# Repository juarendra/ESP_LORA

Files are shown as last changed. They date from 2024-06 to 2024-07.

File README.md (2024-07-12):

# ESP_LORA

ESP-LORA By [Positron Electronik](https://www.tokopedia.com/positronelectronic?source=universe&st=product) is a High-end Development Board with an [ARDUINO UNO-like](https://www.google.com/search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) format, which will speed up your time to make your DIY projects easier.
This board is based on the [ESP32 microcontroller](https://www.espressif.com/sites/default/files/documentation/esp32-wroom-32_datasheet_en.pdf) which makes it an AI-enabled device and is recommended as an Edge Device.
The ESP-LORA By [Positron Electronik](https://www.tokopedia.com/positronelectronic?source=universe&st=product) has three power source inputs -USB, LiPo Battery, DC Jack- that can carry out these options simultaneously. If you use a DC Jack you will get a PSU with a Voltage of 5V 3A.

This board has a LI-PO battery charging feature with a max voltage of 4.2, equipped with Charging Protection so that charging your battery can be done more safely, the charging process can only be done with a USB power source.
By default, the [ESP32 microcontroller](https://www.espressif.com/sites/default/files/documentation/esp32-wroom-32_datasheet_en.pdf) is included with WiFi and Bluetooth Low Energy. This connectivity is even expanded with the presence of the [RFM95W](https://cdn.sparkfun.com/assets/a/e/7/e/b/RFM95_96_97_98W.pdf) LoRa(WAN) module. LoRa(WAN) has a good reputation for low power consumption, complementing the [ESP32 microcontroller](https://www.espressif.com/sites/default/files/documentation/esp32-wroom-32_datasheet_en.pdf)'s sleep mode, making this board even more useful in low-power ecosystems. In conclusion, this is the most appropriate solution for your IoT application.

In terms of design, this board is also equipped with an Industrial SHT21 Hum Temp Sensor and 0.91 inch Oled Display

## Table of Content

* [Product Specsification](#product-specsification)
* [Technical Spesification](#technical-spesification)
* [Priview Hardware](#priview-hardware)
* [Documentation](#documentation)
  * [Pinout Diagram](#pinout-diagram)
  * [Dimension](#dimension)
  * [BOM](#bom)
  * [Schematic](#schematic0)
  * [Example Program](#examples-program)
* [FAQ](#FAQ)

## Product Specsification

* ESP32 as Microcontroller Ready for AI (Tensilica Xtensa single-/dual-core 32-bit LX6 microprocessor(s))
* WiFi & BLE Connectivity 
* LoRa/LoRaWAN Connectivity
* Industrial Temperature Humidity Sensor
* Display Oled 0.91 inch
* Battery Input 1s LiPo with Battery Protection
* Big Power PSU 5V 3A
* Sparated PSU for Microcontroller and LORA

## Technical Spesification

| Features | Value |  
| --- | --- |
| Microcontroller | ESP32 |
| LoRa(WAN) Chip | RFM95W |
| LoRa(WAN) Base Freq | 915 MHz |
| LoRa(WAN) Freq Range | 902-928 MHz |
| Industrial Temperature Humidity Sensor | SHT21 |
| Dispaly | OLED 0.91 inch |
| Main PSU | LM2596 5-30VDC to 5V 3A |
| PSU ESP32 | M3406 2.0V to 6.0V to 3.3V 800mA|
| PSU LORA | M3406 2.0V to 6.0V to 3.3V 800mA| 

## Priview Hardware
<p align="center">
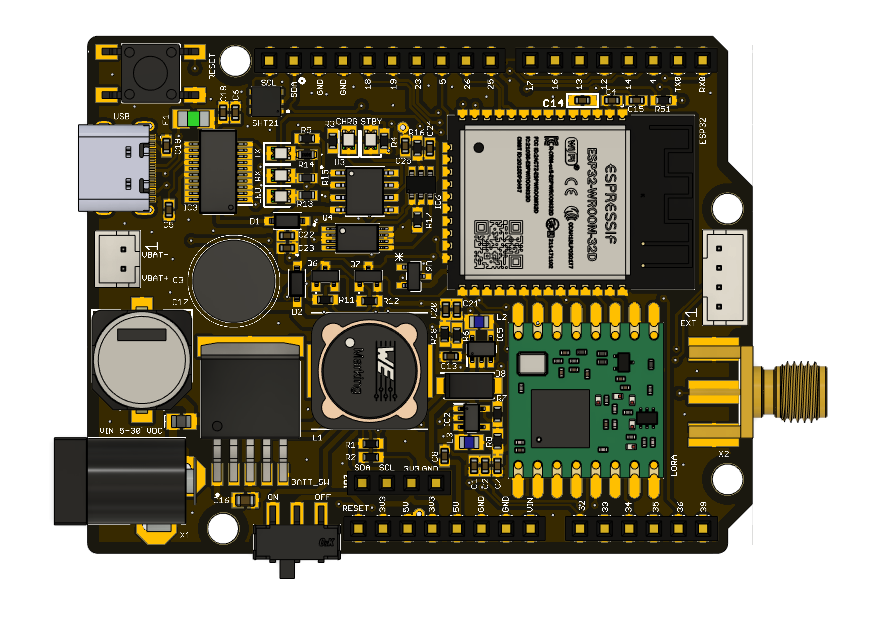
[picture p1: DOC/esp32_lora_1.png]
  
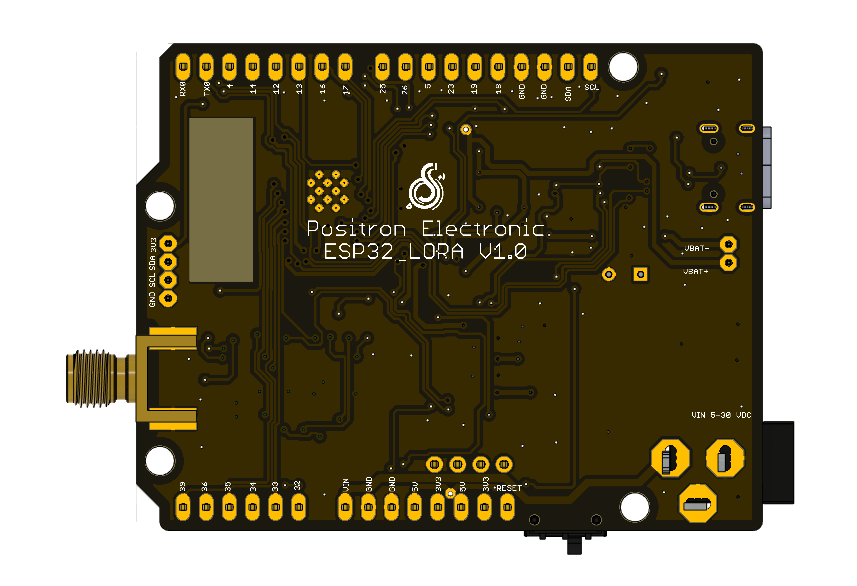
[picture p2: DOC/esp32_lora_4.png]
  
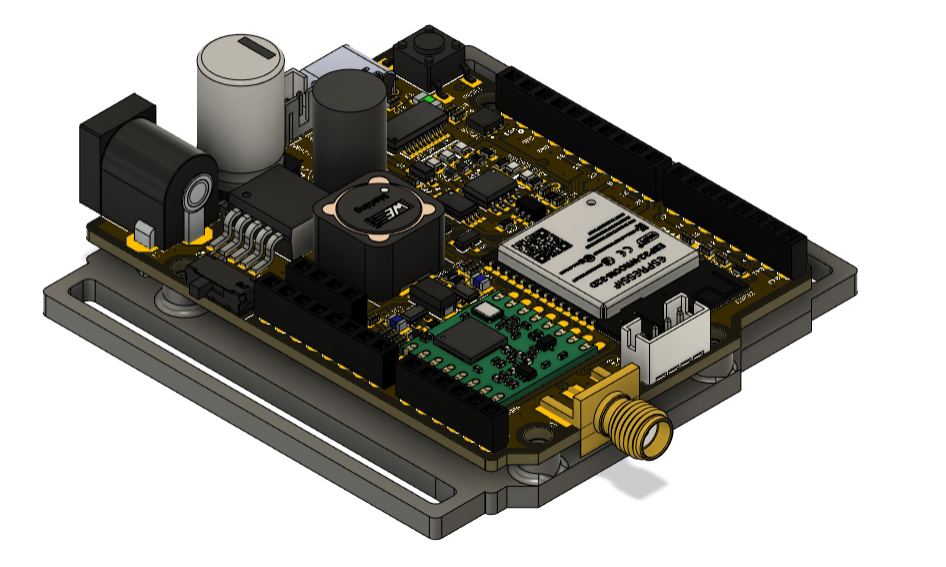
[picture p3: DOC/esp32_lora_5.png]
  
</p>

## Documentation
### Pinout Diagram
* [Pinout diagram](https://github.com/juarendra/ESP_LORA/blob/main/DOC/ESP-LORA-PINOUT.pdf)
* ESP32 to LORA

| ESP32 | LORA |  
| --- | --- |
| GPIO19 | MISO |
| GPIO23 | MOSI |
| GPIO18 | SCK |
| GPIO15 | NSS |
| GPIO0 | RESET |
| GPIO27 | DIO0 |
| GPIO2 | DIO1 |
| GPIO32 | RUN PIN M3406 LORA |

* ESP32 to SHT21

| ESP32 | SHT21 |  
| --- | --- |
| GPIO22 | SCL |
| GPIO21 | SDA |

* ESP32 to OLED

| ESP32 | SHT21 |  
| --- | --- |
| GPIO22 | SCL |
| GPIO21 | SDA |

* ESP32 to LED NOTIF

| ESP32 | LED |  
| --- | --- |
| GPIO2 | KATODE |
| 3V3 | ANODE |

* ESP32 to EXT CONNECTOR

| ESP32 | SHT21 |  
| --- | --- |
| GPIO22 | SCL |
| GPIO21 | SDA |
| 3V3 | 3V3 |
| GND | GND |

### Dimension
* [Dimension Board with Component](https://github.com/juarendra/ESP_LORA/blob/main/HARDWARE/Dimension_ESP32_LORA.pdf)
### BOM
* [BOM Board](https://github.com/juarendra/ESP_LORA/blob/main/HARDWARE/EAGLE/BOM/esp32_lora.csv)
### Schematic
* [Schematic](https://github.com/juarendra/ESP_LORA/blob/main/HARDWARE/EAGLE/PDF/esp32_lora.pdf)
### Example Program

## FAQ

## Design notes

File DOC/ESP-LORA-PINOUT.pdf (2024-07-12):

# ESP32 LORA BY POSITRON ELEKTRONIK

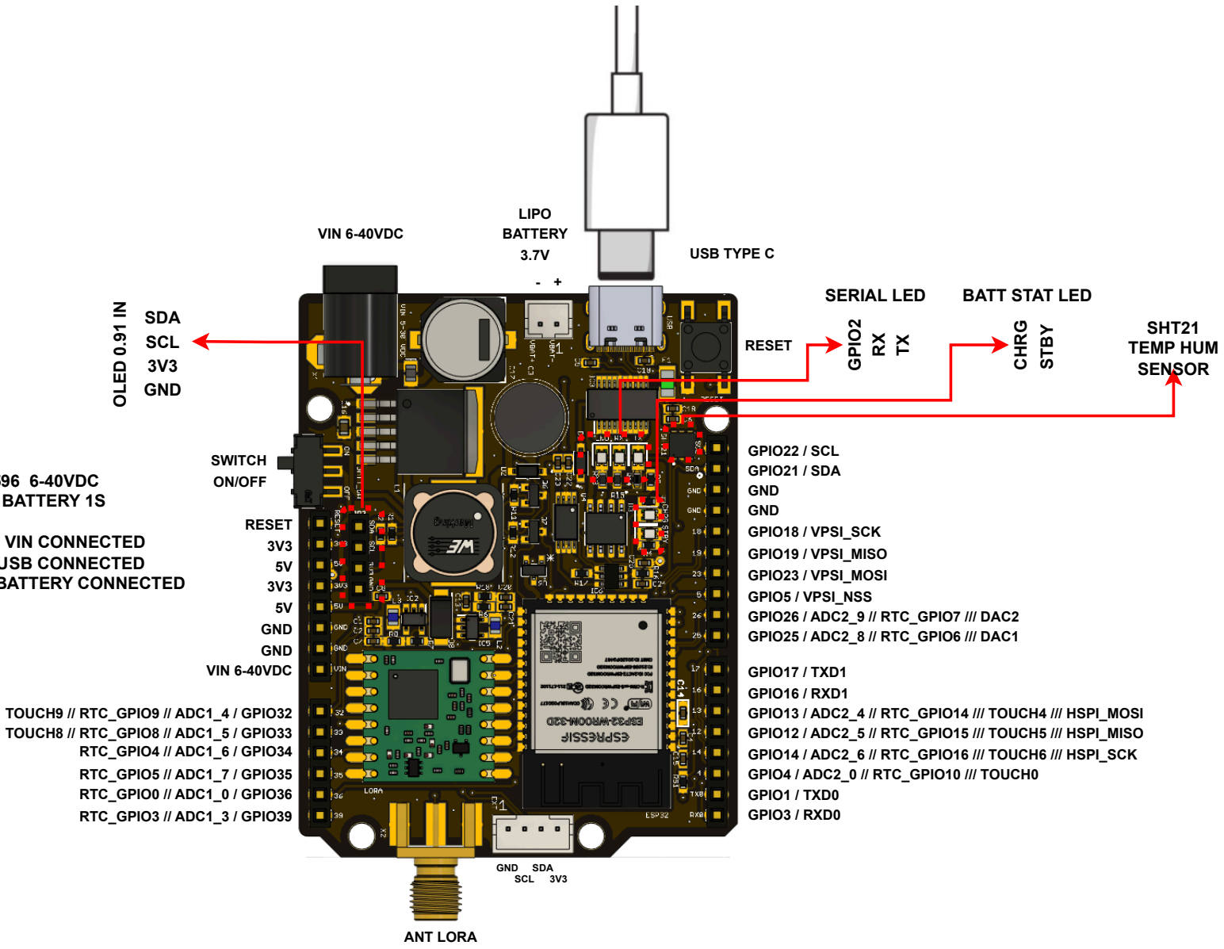
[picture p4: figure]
GPIO22 / SCL GPIO21 / SDA GND GND GPIO18 / VPSI_SCK GPIO19 / VPSI_MISO GPIO23 / VPSI_MOSI GPIO5 / VPSI_NSS GPIO26 / ADC2_9 // RTC_GPIO7 /// DAC2 GPIO25 / ADC2_8 // RTC_GPIO6 /// DAC1; GPIO17 / TXD1 GPIO16 / RXD1; GPIO4 / ADC2_0 // RTC_GPIO10 /// TOUCH0 GPIO1 / TXD0 GPIO3 / RXD0; TOUCH9 // RTC_GPIO9 // ADC1_4 / GPIO32 TOUCH8 // RTC_GPIO8 // ADC1_5 / GPIO33 RTC_GPIO4 // ADC1_6 / GPIO34 RTC_GPIO5 // ADC1_7 / GPIO35 RTC_GPIO0 // ADC1_0 / GPIO36 RTC_GPIO3 // ADC1_3 / GPIO39; VIN 6-40VDC; GND; RESET; ANT LORA; GND SCL; SDA 3V3; USB TYPE C; LIPO BATTERY 3.7V; SWITCH ON/OFF; SDA SCL 3V3 GND; GPIO2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

GPIO13 / ADC2_4 // RTC_GPIO14 /// TOUCH4 /// HSPI_MOSI GPIO12 / ADC2_5 // RTC_GPIO15 /// TOUCH5 /// HSPI_MISO GPIO14 / ADC2_6 // RTC_GPIO16 /// TOUCH6 /// HSPI_SCK

### VOLTAGE RATING

VIN | INPUT VOLTAGE LM2596 6-40VDC
BATTEY | INPUT VOLTAGE LIPO BATTERY 1S
5VDC | OUTPUT LM2596 3A IF VIN CONNECTED
5VDC | OUPUT FROM USB IF USB CONNECTED
5VDC | OUTPUT BATTERY IF BATTERY CONNECTED
3V3 | OUTPUT M3406 0.8A
3V3_LORA | OUTPUT M3406 0.8A

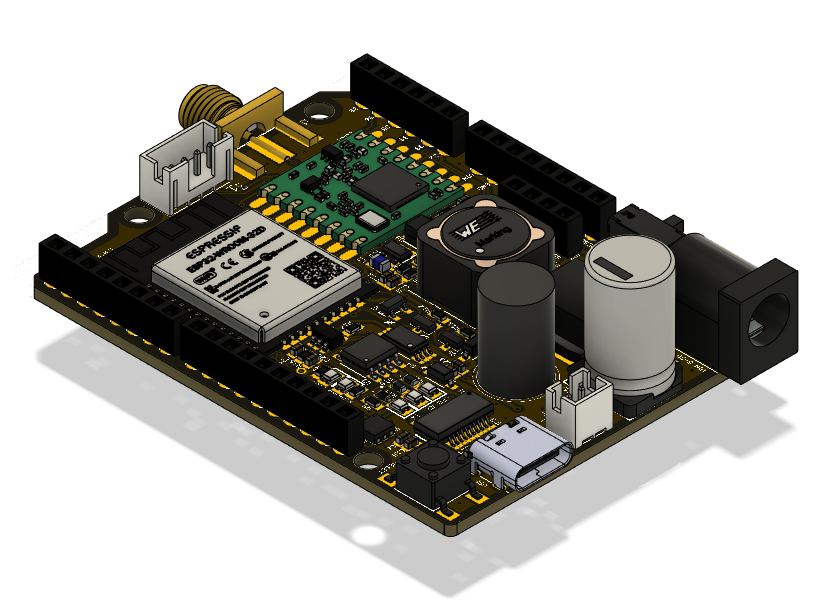
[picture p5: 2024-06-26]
DOC/esp32_lora_3.png

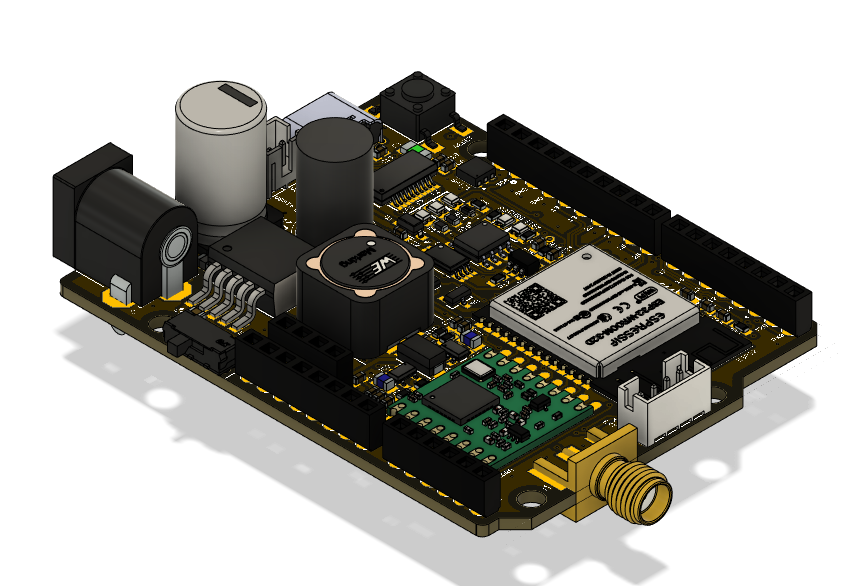
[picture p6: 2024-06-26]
DOC/esp32_lora_2.png

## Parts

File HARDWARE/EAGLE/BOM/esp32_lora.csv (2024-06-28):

Qty | Value | Device | Package | Parts | Description | AVAILABILITY | CHECK_PRICES | DESCRIPTION | DIGIKEY_PARTNUMBER | DIGIKEY_PRICE-STOCK | HEIGHT | LCSC_PART_NUMBER | LCSC_PRICE-STOCK | LENGTH | MANUFACTURER_NAME | MANUFACTURER_PART_NUMBER | MF | MOUSER_PART_NUMBER | MOUSER_PRICE-STOCK | MP | MPN | OC_FARNELL | OC_NEWARK | PACKAGE | POPULARITY | PRICE | PURCHASE-URL | SNAPEDA_LINK | VALUE | WIDTH
1 |  | HEADER-1X4ROUND | 1X04_ROUND | JP3 | PIN HEADER
1 |  | JST-PH2 | JST-PH2 | P1
1 |  | JST-PH4 | JST-PH4 | EXT
2 | 0ZCJ0010FF2E | 0ZCJ0010FF2E | FUSC3216X75N | F1, F2 | Resettable Fuses - PPTC Fuse |  |  | Resettable Fuses - PPTC Fuse |  |  | 0.75mm |  |  |  | BelFuse | 0ZCJ0010FF2E |  | 530-0ZCJ0010FF2E | https://www.mouser.co.uk/ProductDetail/Bel-Fuse/0ZCJ0010FF2E?qs=SRYZG9HaIQ2ZPdy0ahZ08g%3D%3D
1 | 1.2k | ESR03EZPJ102 | RESC1608X55N | R5 | Thick Film Resistors - SMD 0603 1Kohm 5% Anti Surge AEC-Q200 |  |  | Thick Film Resistors - SMD 0603 1Kohm 5% Anti Surge AEC-Q200 | RHM1.0KDCT-ND | https://www.digikey.com/product-detail/en/rohm-semiconductor/ESR03EZPJ102/RHM1-0KDCT-ND/1762924 | 0.55mm |  |  |  | ROHM Semiconductor | ESR03EZPJ102 |  | 755-ESR03EZPJ102 | https://www.mouser.co.uk/ProductDetail/ROHM-Semiconductor/ESR03EZPJ102?qs=DyUWGjl%252BcVvjMuV%252BzioV7Q%3D%3D |  |  |  |  |  |  |  |  |  | 1k
1 | 100 | ESR03EZPJ102 | RESC1608X55N | R16 | Thick Film Resistors - SMD 0603 1Kohm 5% Anti Surge AEC-Q200 |  |  | Thick Film Resistors - SMD 0603 1Kohm 5% Anti Surge AEC-Q200 | RHM1.0KDCT-ND | https://www.digikey.com/product-detail/en/rohm-semiconductor/ESR03EZPJ102/RHM1-0KDCT-ND/1762924 | 0.55mm |  |  |  | ROHM Semiconductor | ESR03EZPJ102 |  | 755-ESR03EZPJ102 | https://www.mouser.co.uk/ProductDetail/ROHM-Semiconductor/ESR03EZPJ102?qs=DyUWGjl%252BcVvjMuV%252BzioV7Q%3D%3D |  |  |  |  |  |  |  |  |  | 1k
11 | 100nf | 885012206071 | CAPC1608X87N | C1, C5, C6, C8, C13, C15, C18, C19, C23, C24, C25 | Wurth Elektronik 0603 WCAP-CSGP 100nF Ceramic Multilayer Capacitor, 25 V dc, +125C, X7R Dielectric, +/-10% |  |  | Wurth Elektronik 0603 WCAP-CSGP 100nF Ceramic Multilayer Capacitor, 25 V dc, +125C, X7R Dielectric, +/-10% | 732-7989-1-ND | https://www.digikey.com/product-detail/en/w%C3%BCrth-elektronik/885012206071/732-7989-1-ND/5454616 | 0.87mm |  |  |  | Wurth Elektronik | 885012206071 |  | 710-885012206071 | https://www.mouser.co.uk/ProductDetail/Wurth-Elektronik/885012206071?qs=0KOYDY2FL2%2FEBQkuHgvarg%3D%3D |  |  |  |  |  |  |  |  |  | 100nf
8 | 10k | ESR03EZPJ103 | RESC1608X55N | R1, R2, R6, R7, R9, R11, R12, R51 | Thick Film Resistors - SMD 0603 10Kohm 5% Anti Surge AEC-Q200 |  |  | Thick Film Resistors - SMD 0603 10Kohm 5% Anti Surge AEC-Q200 | RHM10KDCT-ND | https://www.digikey.com/product-detail/en/rohm-semiconductor/ESR03EZPJ103/RHM10KDCT-ND/1762925 | 0.55mm |  |  |  | ROHM Semiconductor | ESR03EZPJ103 |  | 755-ESR03EZPJ103 | https://www.mouser.com/Search/Refine.aspx?Keyword=755-ESR03EZPJ103 |  |  |  |  |  |  |  |  |  | 10k
3 | 10nf | 885012206089 | CAPC1608X87N | C4, C7, C21 | Wurth Elektronik 0603 WCAP-CSGP 10nF Ceramic Multilayer Capacitor, 50 V dc, +125C, X7R Dielectric, +/-10% |  |  | Wurth Elektronik 0603 WCAP-CSGP 10nF Ceramic Multilayer Capacitor, 50 V dc, +125C, X7R Dielectric, +/-10% | 732-8007-1-ND | https://www.digikey.com/product-detail/en/w%C3%BCrth-elektronik/885012206089/732-8007-1-ND/5454634 | 0.87mm |  |  |  | Wurth Elektronik | 885012206089 |  | 710-885012206089 | https://www.mouser.co.uk/ProductDetail/Wurth-Elektronik/885012206089?qs=0KOYDY2FL28GvSbKh319Tw%3D%3D |  |  |  |  |  |  |  |  |  | 10nf
1 | 10x1F-H8.5 | PINHD-1X10_ARD | 1X10 | IOH | PIN HEADER
1 | 1N5819HW-7 | 1N5819HW-7 | SOD3715X145N | D1 | 1N5819HW Series 40 V 1 A Surface Mount Schottky Barrier Rectifier - SOD-123 Check availability | In Stock | https://www.snapeda.com/parts/1N5819HW-7/Diodes+Inc./view-part/?ref=eda | Diode Schottky 40 V 1A Surface Mount SOD-123 |  |  |  |  |  |  |  |  | Diodes Inc. |  |  | 1N5819HW-7 |  |  |  | SOD-123 Fairchild Semiconductor |  | None | https://www.snapeda.com/api/url_track_click_mouser/?unipart_id=51510&manufacturer=Diodes Inc.&part_name=1N5819HW-7&search_term=1n5819 | https://www.snapeda.com/parts/1N5819HW-7/Diodes+Inc./view-part/?ref=snap
3 | 1k | ESR03EZPJ102 | RESC1608X55N | R3, R4, R17 | Thick Film Resistors - SMD 0603 1Kohm 5% Anti Surge AEC-Q200 |  |  | Thick Film Resistors - SMD 0603 1Kohm 5% Anti Surge AEC-Q200 | RHM1.0KDCT-ND | https://www.digikey.com/product-detail/en/rohm-semiconductor/ESR03EZPJ102/RHM1-0KDCT-ND/1762924 | 0.55mm |  |  |  | ROHM Semiconductor | ESR03EZPJ102 |  | 755-ESR03EZPJ102 | https://www.mouser.co.uk/ProductDetail/ROHM-Semiconductor/ESR03EZPJ102?qs=DyUWGjl%252BcVvjMuV%252BzioV7Q%3D%3D |  |  |  |  |  |  |  |  |  | 1k
1 | 1uF | CAP_CERAMIC0603 | 0603 | C14 | Ceramic Capacitors
2 | 1uf | 885012206071 | CAPC1608X87N | C2, C20 | Wurth Elektronik 0603 WCAP-CSGP 100nF Ceramic Multilayer Capacitor, 25 V dc, +125C, X7R Dielectric, +/-10% |  |  | Wurth Elektronik 0603 WCAP-CSGP 100nF Ceramic Multilayer Capacitor, 25 V dc, +125C, X7R Dielectric, +/-10% | 732-7989-1-ND | https://www.digikey.com/product-detail/en/w%C3%BCrth-elektronik/885012206071/732-7989-1-ND/5454616 | 0.87mm |  |  |  | Wurth Elektronik | 885012206071 |  | 710-885012206071 | https://www.mouser.co.uk/ProductDetail/Wurth-Elektronik/885012206071?qs=0KOYDY2FL2%2FEBQkuHgvarg%3D%3D |  |  |  |  |  |  |  |  |  | 100nf
1 | 2.2uf | KAF21KR71H225KU | CAPC2012X140N | C16 | Multilayer Ceramic Capacitors MLCC - SMD/SMT 50V 2.2uF X7R 0805 10% AEC-Q200 FLEXITERM |  |  | Multilayer Ceramic Capacitors MLCC - SMD/SMT 50V 2.2uF X7R 0805 10% AEC-Q200 FLEXITERM |  |  | 1.4mm |  |  |  | Kyocera AVX | KAF21KR71H225KU |  | 581-KAF21KR71H225KU | https://www.mouser.co.uk/ProductDetail/KYOCERA-AVX/KAF21KR71H225KU?qs=Jm2GQyTW%2FbjwwNTLmtUMeQ%3D%3D
1 | 220uf 25V | MAL203836221E3 | CAPPRD350W60D850H1250 | C3 | VISHAY - MAL203836221E3 - CAP, 220F, 25V, 20% |  |  | VISHAY - MAL203836221E3 - CAP, 220F, 25V, 20% |  |  | 12.5mm |  |  |  | Vishay | MAL203836221E3 |  | 594-MAL203836221E3 | https://www.mouser.co.uk/ProductDetail/Vishay-BC-Components/MAL203836221E3?qs=G99oyVYclWUIwcN6B3qC5w%3D%3D
3 | 330 | ERJ-H3EF3300V | ERJH3 | R13, R14, R15 | Power Rating 0.125W,Resistance 330 Ohm,LxW(EIA) 1.6 x 0.8 (EIA:0603) mm |  |  | Power Rating 0.125W,Resistance 330 Ohm,LxW(EIA) 1.6 x 0.8 (EIA:0603) mm |  |  | mm |  |  |  | Panasonic | ERJ-H3EF3300V |  | 667-ERJ-H3EF3300V | https://www.mouser.co.uk/ProductDetail/Panasonic/ERJ-H3EF3300V?qs=eP2BKZSCXI61roRLPi8W7w%3D%3D |  |  |  |  |  |  |  |  |  | 330
1 | 33uh 12x12 | 744770133 | WE-PD_1260/1245/1280/121054 | L1 | Wurth WE-PD Series Shielded Wire-wound SMD Inductor with a Ferrite Core, 33 uH +/-20% 3.6A Idc |  |  | Wurth WE-PD Series Shielded Wire-wound SMD Inductor with a Ferrite Core, 33 uH +/-20% 3.6A Idc |  |  | mm |  |  |  | Wurth Elektronik | 744770133 |  | 710-744770133 | https://www.mouser.co.uk/ProductDetail/Wurth-Elektronik/744770133?qs=E%2F%2FhvbtCqpPKkGJl8TxFXw%3D%3D
2 | 40k2 | ERJ-S03F4022V | RESC1608X55N | R8, R18 | Thick Film Resistors - SMD 0603 40.2Kohms 1% Anti-Sulfur |  |  | Thick Film Resistors - SMD 0603 40.2Kohms 1% Anti-Sulfur |  |  | 0.55mm |  |  |  | Panasonic | ERJ-S03F4022V |  | 667-ERJ-S03F4022V | https://www.mouser.com/Search/Refine.aspx?Keyword=667-ERJ-S03F4022V
1 | 680uf | EEH-ZU1V681UP | EEHZS1H221P | C17 | Conductive Polymer Hybrid Aluminum Electrolytic Capacitor |  |  | Conductive Polymer Hybrid Aluminum Electrolytic Capacitor |  |  | 10.5mm |  |  |  | Panasonic | EEH-ZU1V681UP |  | 667-EEH-ZU1V681UP | https://www.mouser.co.uk/ProductDetail/Panasonic/EEH-ZU1V681UP?qs=HoCaDK9Nz5elLexP3akqig%3D%3D
1 | 6x1F-H8.5 | PINHD-1X6 | 1X06 | AD | PIN HEADER
2 | 8x1F-H8.5 | PINHD-1X8 | 1X08 | IOL, POWER | PIN HEADER
1 | B340A-13-F | B340A-13-F | DIOM5226X240N | D8 | Schottky Diode 3A 40V 0.5Vf SMA Diodes Inc B340A-13-F, SMT Schottky Diode, 40V 3A, 2-Pin DO-214AC |  |  | Schottky Diode 3A 40V 0.5Vf SMA Diodes Inc B340A-13-F, SMT Schottky Diode, 40V 3A, 2-Pin DO-214AC |  |  | 2.4mm |  |  |  | Diodes Incorporated | B340A-13-F |  | 621-B340A-F | https://www.mouser.co.uk/ProductDetail/Diodes-Incorporated/B340A-13-F?qs=aLaTXeBcTP9fj%2FYKVo6Q1A%3D%3D
1 | DW01A | DW01A | SOT23-6 | IC6 | Check availability | Not in stock | https://www.snapeda.com/parts/DW01A/Fortune+Semiconductor/view-part/?ref=eda | One Cell Lithium-ion/Polymer Battery Protection IC |  |  |  |  |  |  |  |  | Fortune Semiconductor |  |  | DW01A |  |  |  | SOT-23-6 Fortune Semiconductor |  | None |  | https://www.snapeda.com/parts/DW01A/Fortune+Semiconductor/view-part/?ref=snap
1 | ESP32-WROOM-32D | ESP32-WROOM-32D | MODULE_ESP32-WROOM-32D | ESP32 | Bluetooth, WiFi 802.11b/g/n, Bluetooth v4.2 + EDR, Class 1, 2 and 3 Transceiver Module 2.4GHz ~ 2.5GHz Integrated, Trace Surface Mount Check availability | In Stock |  | Bluetooth, WiFi 802.11b/g/n, Bluetooth v4.2 +EDR, Class 1, 2 and 3 Transceiver Module 2.4GHz ~ 2.5GHz Integrated |  |  |  |  |  |  |  |  | Espressif Systems |  |  | ESP32-WROOM-32D |  |  |  | Module Espressif Systems |  | None | https://pricing.snapeda.com/search/part/ESP32-WROOM-32D/?ref=eda
1 | FS8205A | FS8205A | SOP65P640X120-8N | Q4 | N/A Check availability | Not in stock | https://www.snapeda.com/parts/FS8205A/Fortune+Semiconductor/view-part/?ref=eda |  |  |  |  |  |  |  |  |  | Fortune Semiconductor |  |  | FS8205A |  |  |  | Package |  | None |  | https://www.snapeda.com/parts/FS8205A/Fortune+Semiconductor/view-part/?ref=snap
1 | FSM2JSMAATR | FSM2JSMAATR | FSM2J_1 | RESET | Tactile switch,SMT,SPST,raised white act |  |  | Tactile switch,SMT,SPST,raised white act |  |  | mm |  |  |  | TE Connectivity | FSM2JSMAATR |  | 506-FSM2JSMAATR | https://www.mouser.co.uk/ProductDetail/TE-Connectivity-Alcoswitch/FSM2JSMAATR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
1 | FT231XS-R | FT231XS-R | SOP64P599X175-20N | IC3 | FTDI Chip FT231XS-R, Interface RS232, RS422, RS485, SIE, UART 3MBd, 5 V, 20-pin, SSOP |  |  | FTDI Chip FT231XS-R, Interface RS232, RS422, RS485, SIE, UART 3MBd, 5 V, 20-pin, SSOP |  |  | 1.753mm |  |  |  | FTDI Chip | FT231XS-R |  | 895-FT231XS-R | https://www.mouser.co.uk/ProductDetail/FTDI/FT231XS-R?qs=Gp1Yz1mis3WduRPsgrTbtg%3D%3D
5 | Green | 150080BS75000 | LEDC2012X80N | CHRG, LED, RX, STBY, TX | LED,Wurth Elektronik,150080BS75000 Wurth Elektronik 150080BS75000, WL-SMCW Series Blue LED, 470 nm 2012 (0805) Clear, Rectangle Lens SMD package |  |  | LED,Wurth Elektronik,150080BS75000 Wurth Elektronik 150080BS75000, WL-SMCW Series Blue LED, 470 nm 2012 (0805) Clear, Rectangle Lens SMD package |  |  | 0.8mm |  |  |  | Wurth Elektronik | 150080BS75000 |  | 710-150080BS75000 | https://www.mouser.co.uk/ProductDetail/Wurth-Elektronik/150080BS75000?qs=2kOmHSv6VfT2tBo3UPVqAQ%3D%3D |  |  |  |  |  |  |  |  |  | Green
1 | HOPERF_RFM95W | HOPERF_RFM95W | HOPERF_RFM95W | U$1 | HopeRF LoRaWAN modules |  |  |  |  |  | 1.8 |  |  | 16 |  |  |  |  |  |  |  |  |  |  |  |  |  |  |  | 16
1 | JS102011SAQN | JS102011SAQN | SW_JS102011SAQN | BATT_SW | <b> | In Stock | https://www.snapeda.com/parts/JS102011SAQN/C%2526K/view-part/?ref=eda | Slide Switch SPDT Surface Mount, Right Angle |  |  |  |  |  |  |  |  | C&K |  |  | JS102011SAQN |  |  |  | None |  | None | https://pricing.snapeda.com/search?q=JS102011SAQN&ref=eda | https://www.snapeda.com/parts/JS102011SAQN/C%2526K/view-part/?ref=snap
1 | LM2596SX-5.0_NOPB | LM2596SX-5.0_NOPB | KTT0005B | IC1 | SIMPLE SWITCHER&#174; 4.5V to 40V, 3A Low Component Count Step-Down Regulator |  |  | SIMPLE SWITCHER&#174 | 4.5V to 40V, 3A Low Component Count Step-Down Regulator |  |  | mm |  |  |  | Texas Instruments | LM2596SX-5.0/NOPB |  | 926-LM2596SX-5.0NOPB | https://www.mouser.co.uk/ProductDetail/Texas-Instruments/LM2596SX-5.0-NOPB?qs=X1J7HmVL2ZGZ5T4VcWdmNw%3D%3D
2 | M3406-ADJ | M3406-ADJ | SOT95P280X100-5N | IC2, IC5 | Step-down type SOT-23-5 DC-DC Converters ROHS |  |  | Step-down type SOT-23-5 DC-DC Converters ROHS |  |  | 1mm | C83224 | https://www.lcsc.com/product-detail/DC-DC-Converters_XI-AN-Aerosemi-Tech-M3406-ADJ_C83224.html |  | XI'AN Aerosemi Tech | M3406-ADJ
2 | MLF2012A2R2KT000 | MLF2012A2R2KT000 | INDC2012X105N | L2, L3 | 2.2 H Shielded Multilayer Inductor 50 mA 500mOhm Max 0805 (2012 Metric) |  |  | 2.2 H Shielded Multilayer Inductor 50 mA 500mOhm Max 0805 (2012 Metric) |  |  | 1.05mm |  |  |  | TDK | MLF2012A2R2KT000 |  | 810-MLF2012A2R2KT000 | https://www.mouser.co.uk/ProductDetail/TDK/MLF2012A2R2KT000?qs=pLY5GE0xrmL3Y2Jw%2FEGjFg%3D%3D
2 | MMBT3904-TP | MMBT3904-TP | SI2305TP | Q6, Q7 | Bipolar Transistors - BJT 40V |  |  | Bipolar Transistors - BJT 40V |  |  | mm |  |  |  | Micro Commercial Components (MCC) | MMBT3904-TP |  | 833-MMBT3904-TP | https://www.mouser.co.uk/ProductDetail/Micro-Commercial-Components-MCC/MMBT3904-TP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
1 | POWERSUPPLY_DC21MMX | POWERSUPPLY_DC21MMX | POWERSUPPLY_DC-21MM | X1
1 | SHT21 | SHT21 | XDCR_SHT21 | SHT21 | Check availability | In Stock | https://www.snapeda.com/parts/SHT21/Sensirion+AG/view-part/?ref=eda | SENSOR HUMID/TEMP 3V I2C 2% SMD |  |  |  |  |  |  |  |  | Sensirion AG |  |  | SHT21 |  |  |  | DFN-6 Sensirion |  | None | https://www.snapeda.com/api/url_track_click_mouser/?unipart_id=46060&manufacturer=Sensirion AG&part_name=SHT21&search_term=None | https://www.snapeda.com/parts/SHT21/Sensirion+AG/view-part/?ref=snap
1 | SI2301BDS-T1-E3 | SI2301BDS-T1-E3 | SOT95P237X112-3N | U6 | MOSFET Check availability | In Stock | https://www.snapeda.com/parts/SI2301BDS-T1-E3/Vishay+Siliconix/view-part/?ref=eda | MOSFET,P-Ch,VDSS -20V,RDS(ON) 0.08Ohm,ID -2.2A,TO-236 (SOT-23),PD 0.7W,VGS +/-8V | Siliconix / Vishay SI2301BDS-T1-E3 |  |  |  |  |  |  |  |  | Vishay |  |  | SI2301BDS-T1-E3 |  |  |  | SOT-23-3 Vishay Siliconix |  | None | https://www.snapeda.com/api/url_track_click_mouser/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 | https://www.snapeda.com/parts/SI2301BDS-T1-E3/Vishay+Siliconix/view-part/?ref=snap
1 | SMA-142-0701-801/806 | SMA-142-0701-801/806 | J502-ND-142-0701-801/806 | X2 | SMA 50 Ohm End Launch Jack Receptacle - Round Contact |  |  |  |  |  |  |  |  |  |  |  | JOHNSON COMPONENTS |  |  |  | 142-0701-801 | 1608592 | 90F2624 |  | 5
1 | TP4056 | TP4056 | SOP127P600X175-9N | U3 | Complete single cell Li-Ion battery with a constant current / constant voltage linear charger Check availability | Not in stock | https://www.snapeda.com/parts/TP4056/NanJing+Top+Power+ASIC+Corp./view-part/?ref=eda | Complete single cell Li-Ion battery with a constant current / constant voltage linear charger |  |  |  |  |  |  |  |  | NanJing Top Power ASIC Corp. |  |  | TP4056 |  |  |  | Package |  | None |  | https://www.snapeda.com/parts/TP4056/NanJing+Top+Power+ASIC+Corp./view-part/?ref=snap
1 | TYPE-C-31-M-12 | TYPE-C-31-M-12 | HRO_TYPE-C-31-M-12 | USB | Check availability | Not in stock | https://www.snapeda.com/parts/TYPE-C-31-M-12/HRO+Electronics+Co.%252C+Ltd./view-part/?ref=eda | USB Connectors 24 Receptacle 1 8.94*7.3mm RoHS |  |  |  |  |  |  |  |  | HRO Electronics Co., Ltd. |  |  | TYPE-C-31-M-12 |  |  |  | Package |  | None |  | https://www.snapeda.com/parts/TYPE-C-31-M-12/HRO+Electronics+Co.%252C+Ltd./view-part/?ref=snap

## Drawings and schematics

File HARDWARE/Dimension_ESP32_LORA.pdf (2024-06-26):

51.34 66.04 68.72

9.52 ⁷.62 | 1. TOP VIEW ³. SIDE VIEW | 2. SIDE VIEW 6.SIDE VIEW | 4.SIDE VIEW | 8.BACK VIEW | 7. ISOMETRIC VIEW

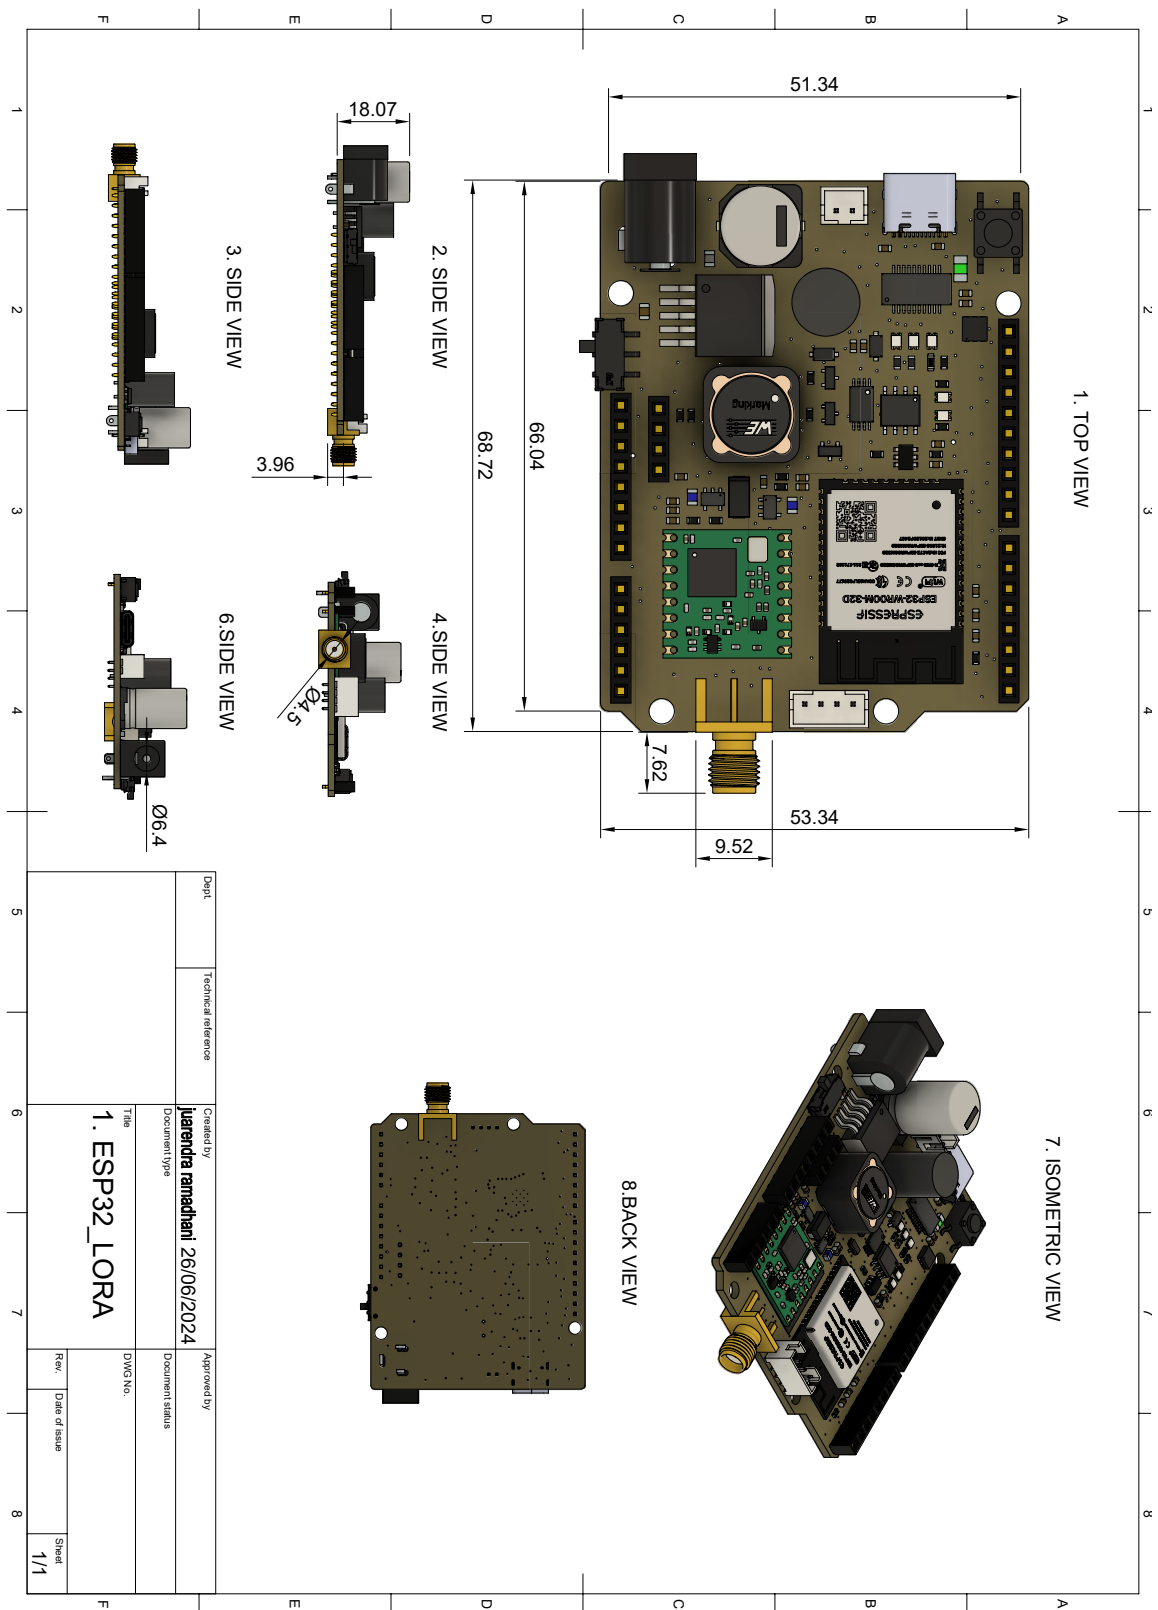
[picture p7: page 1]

1 A 2 3 4 5 6 7 8 1 2 3 4 5 6 7 8 FEDCB FEDCBA Dept. Technical reference Created by Approved by Title DWG No. Document type Document status Rev. Date of issue Sheet 26/06/2024 1/1 1. ESP32_LORA

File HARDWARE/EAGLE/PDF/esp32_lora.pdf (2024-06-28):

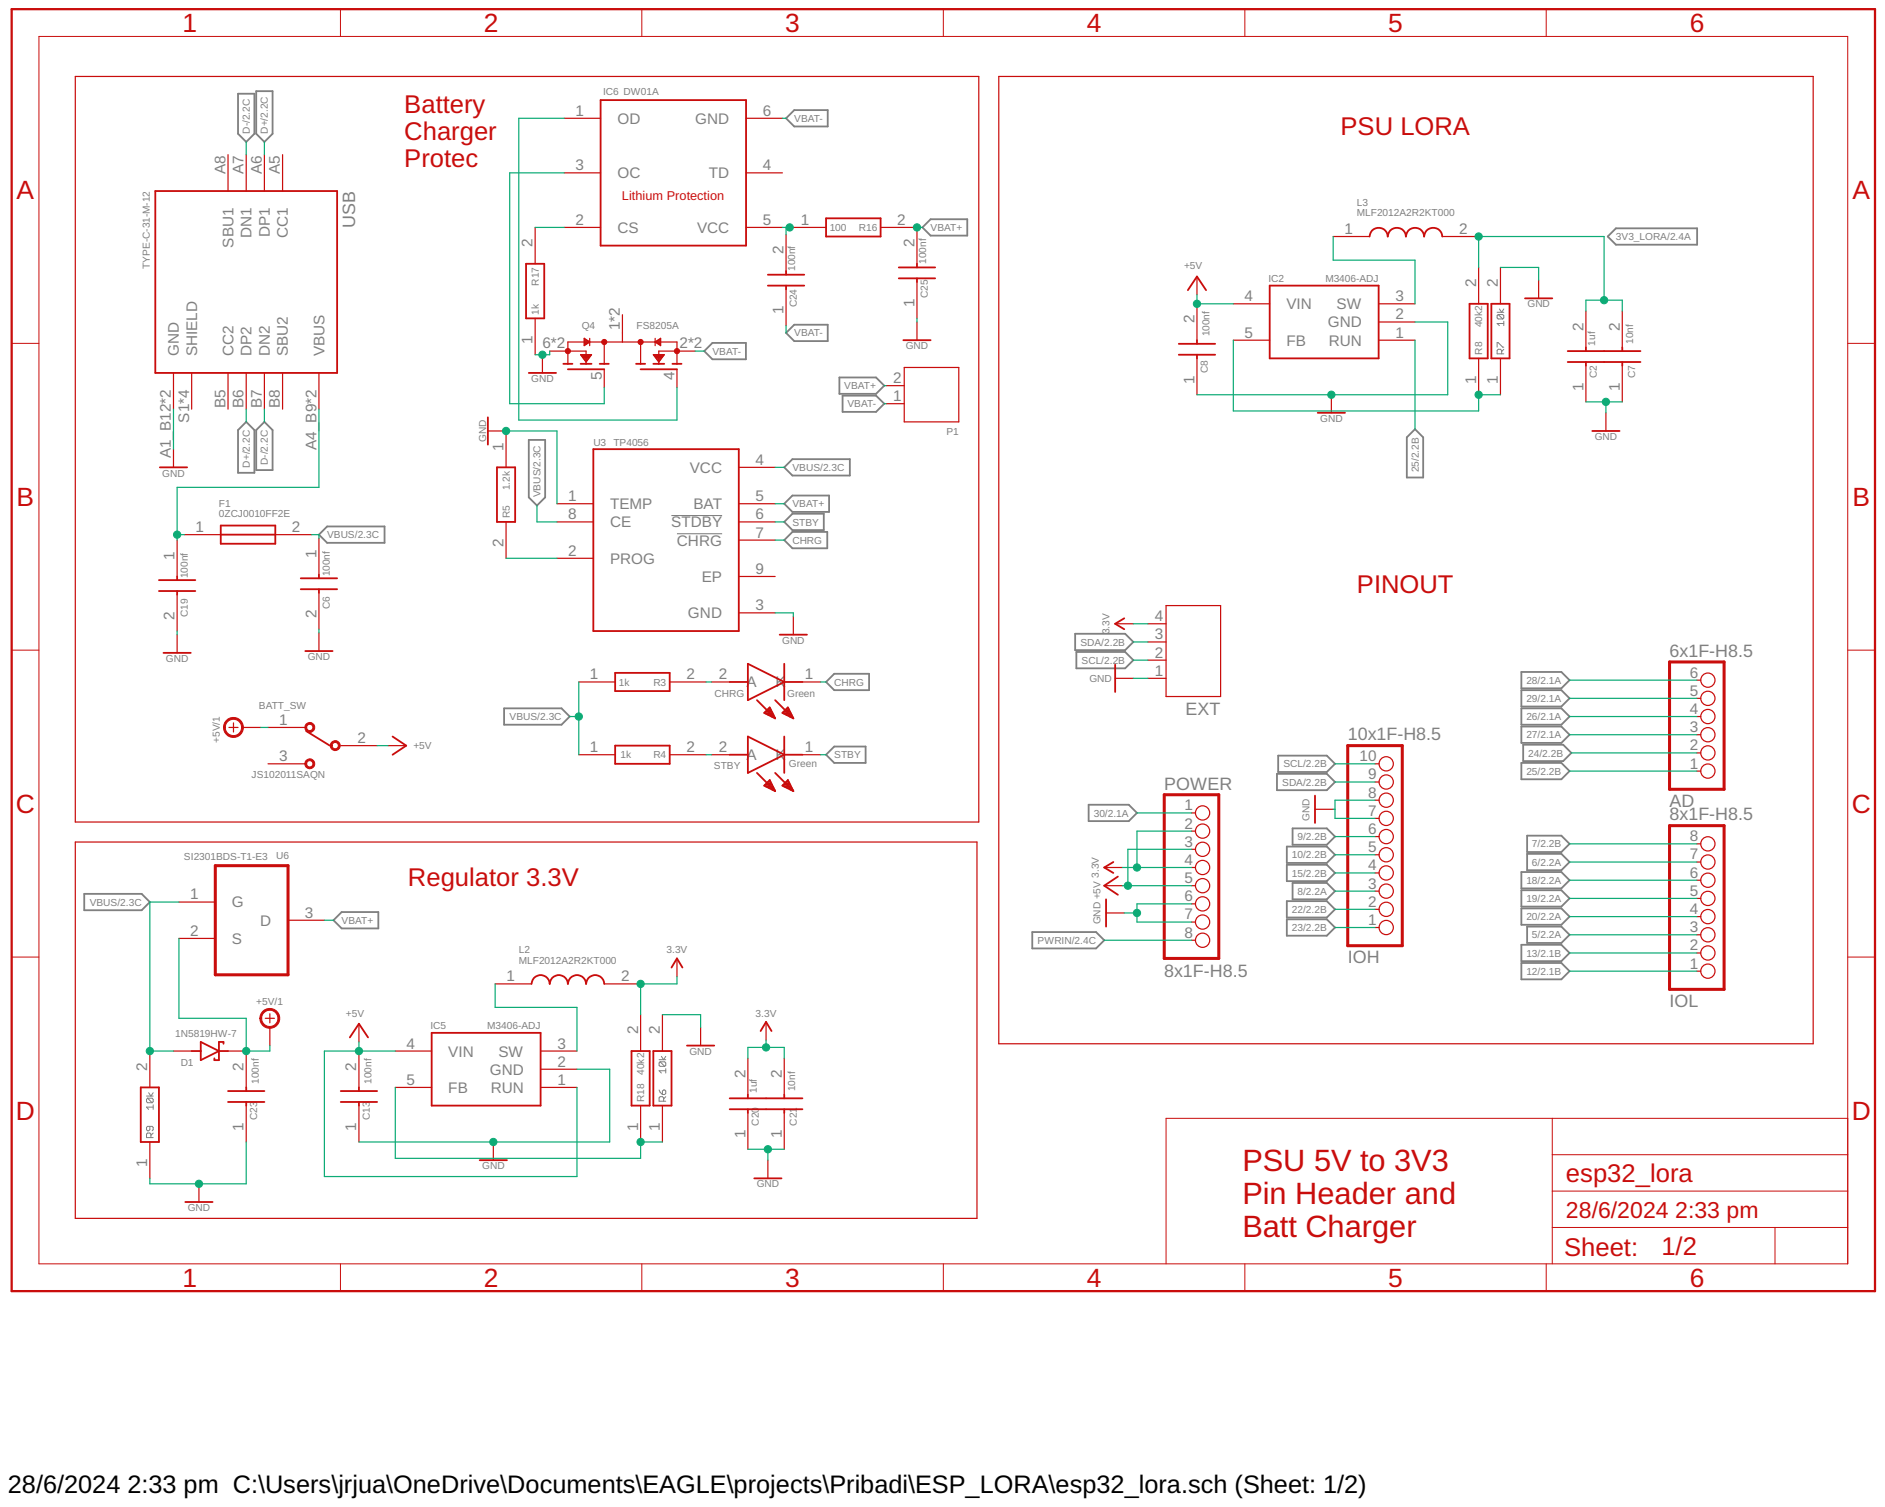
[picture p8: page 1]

PSU 5V to 3V3 Pin Header and Batt Charger

Sheet: 1/2

28/6/2024 2:33 pm C:\Users\jrjua\OneDrive\Documents\EAGLE\projects\Pribadi\ESP_LORA\esp32_lora.sch (Sheet: 1/2)

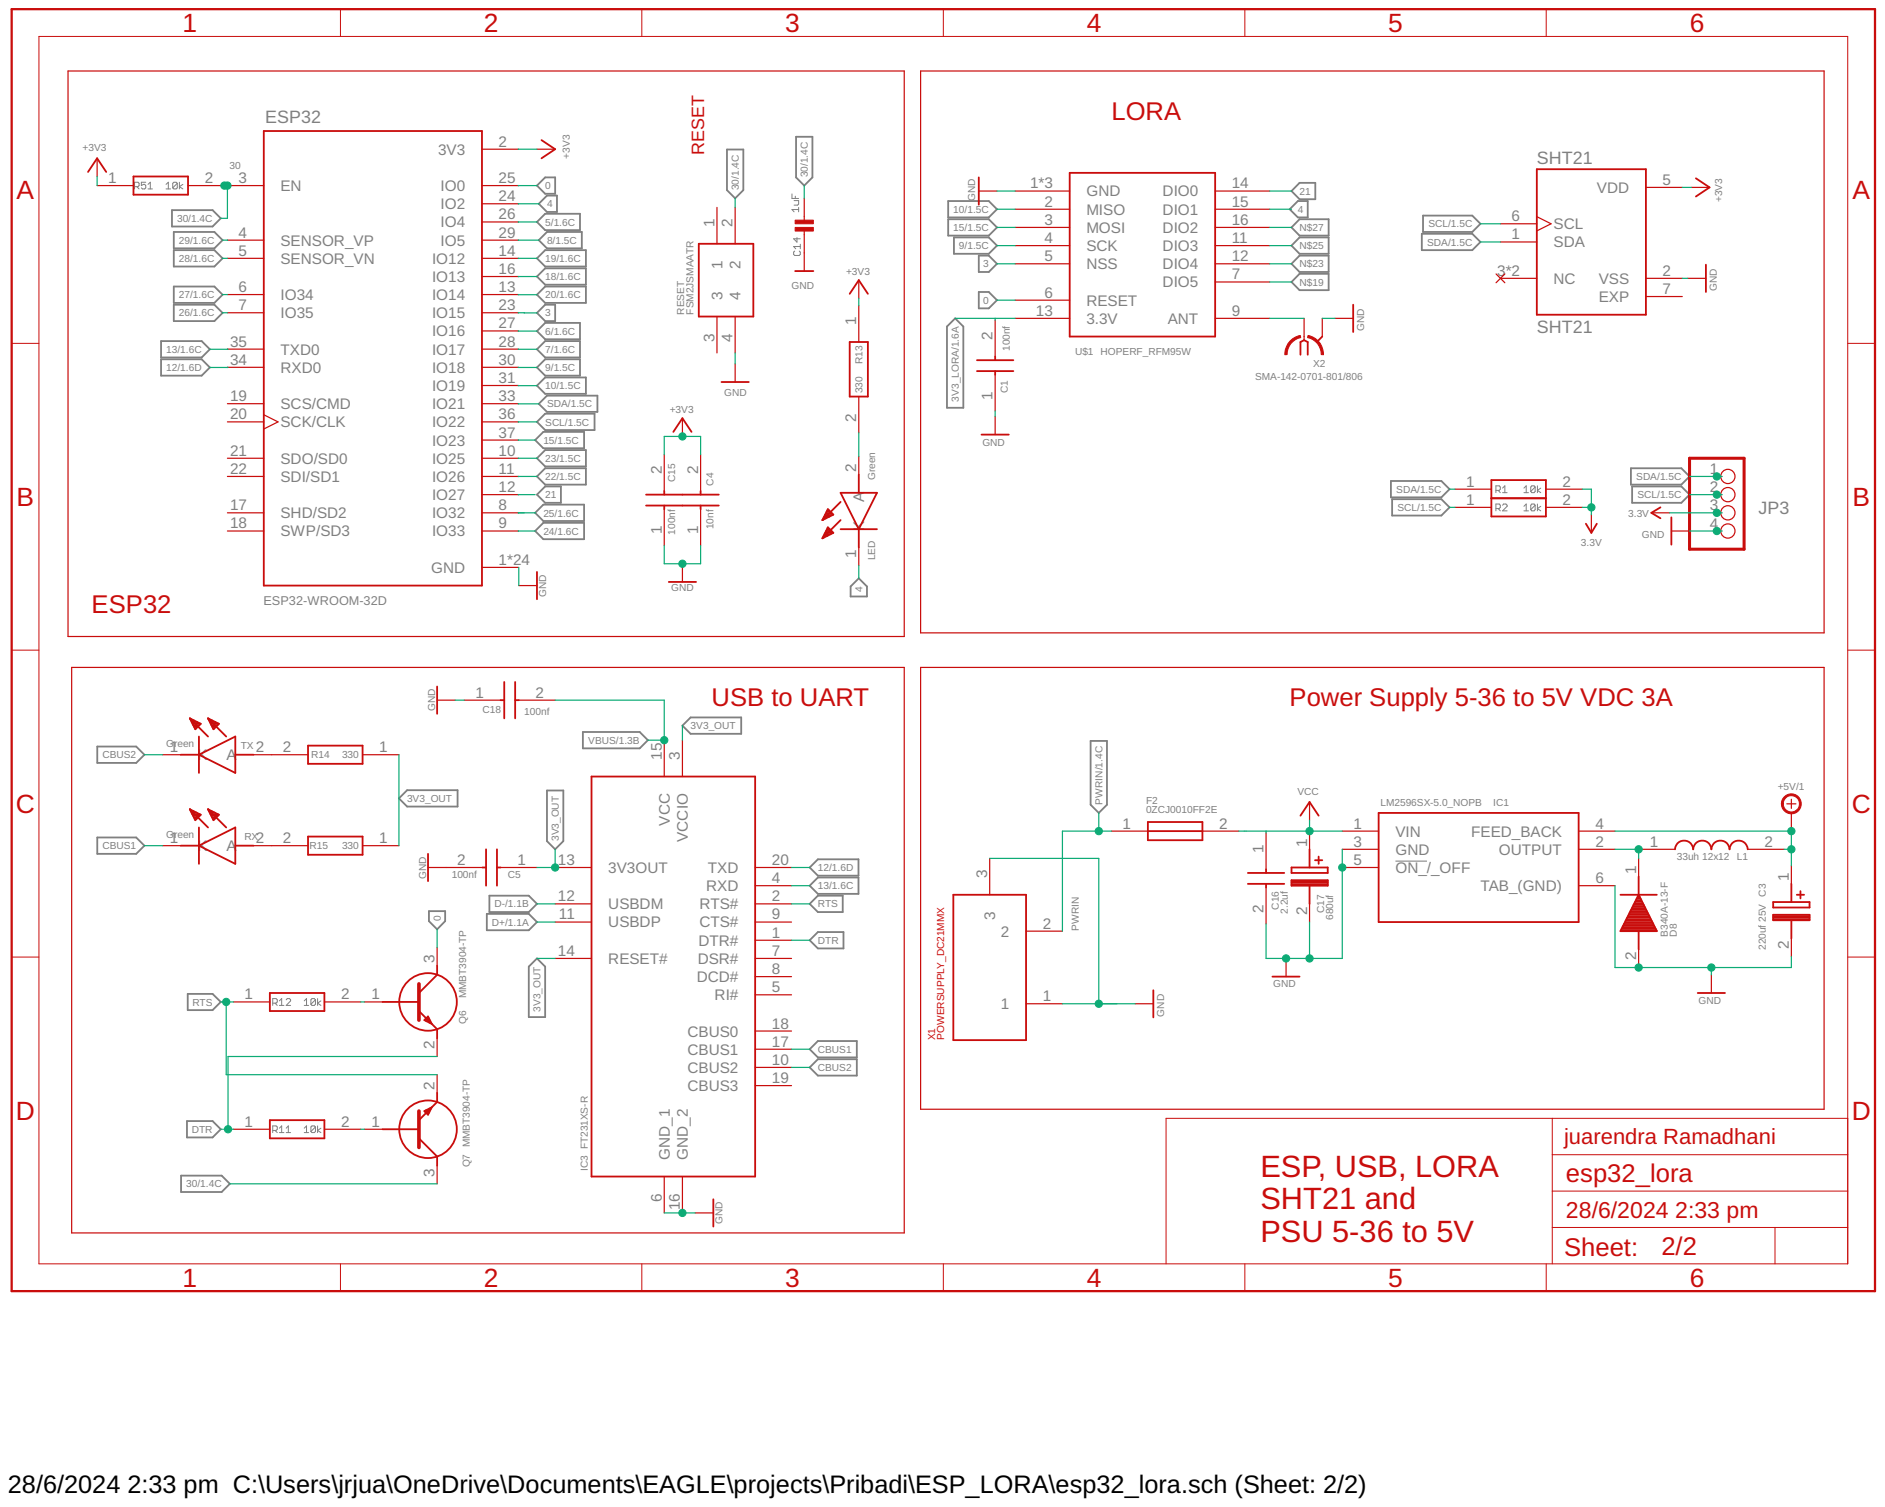
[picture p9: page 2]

Power Supply 5-36 to 5V VDC 3A

28/6/2024 2:33 pm C:\Users\jrjua\OneDrive\Documents\EAGLE\projects\Pribadi\ESP_LORA\esp32_lora.sch (Sheet: 2/2)

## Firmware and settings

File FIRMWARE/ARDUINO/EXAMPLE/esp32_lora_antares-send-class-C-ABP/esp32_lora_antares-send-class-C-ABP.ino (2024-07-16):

/* Copyright 2024 Juarendra Ramadhani <jrjuarendra@gmail.com>
 *
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
 * You should have received a copy of the GNU General Public License
 * along with this program.  If not, see <http://www.gnu.org/licenses/>.
 */
#include <SPI.h>
#include <lorawan.h>

//define the pins used by the transceiver module
#define LORA_NSS 15
#define LORA_RST 0
#define LORA_DIO0 27
#define LORA_DIO1 2
#define LORA_EN 32


//ABP Credentials
const char *devAddr = "your-antares-device-address";
const char *nwkSKey = "your-antares-network-session-key";
const char *appSKey = "your-antares-application-session-key";

const unsigned long interval = 10000;    // 10 s interval to send message
unsigned long previousMillis = 0;  // will store last time message sent
unsigned int counter = 0;     // message counter

char myStr[50];
byte outStr[255];
byte recvStatus = 0;
int port, channel, freq;
bool newmessage = false;

const sRFM_pins RFM_pins = {
  .CS   = LORA_NSS,
  .RST  = LORA_RST,
  .DIO0 = LORA_DIO0,
  .DIO1 = LORA_DIO1,
};

#include "modified_font.h"

/*  SSD1306 */
#include "SSD1306.h" 
#define SDA_PIN 21
#define SCL_PIN 22
#define SSD_ADDRESS 0x3c
SSD1306  display(SSD_ADDRESS, SDA_PIN, SCL_PIN);

/* SHT21 */
#include "Wire.h"
#include "SHT2x.h"
uint32_t start;
uint32_t stop;

float localHum = 0;
float localTemp = 0;

SHT2x sht;

void setup() {
  // Initiate the LoRa Enable pin
  pinMode(LORA_EN, OUTPUT);
  // LoRa chip is Active High
  digitalWrite(LORA_EN, HIGH);

  //initialize Serial Monitor
  Serial.begin(115200);
  while (!Serial);
  Serial.println("LoRa Sender");
  delay(2000);

  if (!lora.init()) {
    Serial.println("RFM95 not detected");
    delay(5000);
    return;
  }
  // Set LoRaWAN Class change CLASS_A or CLASS_C
  lora.setDeviceClass(CLASS_C);

  // Set Data Rate
  lora.setDataRate(SF12BW125);

  // Set FramePort Tx
  lora.setFramePortTx(5);

  // set channel to random
  lora.setChannel(MULTI);

  // Set TxPower to 15 dBi (max)
  lora.setTxPower(15);

  // Put ABP Key and DevAddress here
  lora.setNwkSKey(nwkSKey);
  lora.setAppSKey(appSKey);
  lora.setDevAddr(devAddr);

  Serial.println(__FILE__);
  Serial.print("SHT2x_LIB_VERSION: \t");
  Serial.println(SHT2x_LIB_VERSION);

  Wire.begin(SDA_PIN, SCL_PIN);
  sht.begin();

  uint8_t stat = sht.getStatus();
  Serial.print(stat, HEX);
  Serial.println();

  display.init();

  display.flipScreenVertically();
  display.setTextAlignment(TEXT_ALIGN_LEFT);
  display.setFont(Open_Sans_Condensed_Light_20); 
  
}

void loop() {

  // Check interval overflow
  if (millis() - previousMillis > interval) {
    previousMillis = millis();

    sprintf(myStr, "Lora Counter-%d", counter++);

    
    Serial.print("Sending: ");
    Serial.println(myStr);
    lora.sendUplink(myStr, strlen(myStr), 0);
    port = lora.getFramePortTx();
    channel = lora.getChannel();
    freq = lora.getChannelFreq(channel);
    Serial.print(F("fport: "));    Serial.print(port);Serial.print(" ");
    Serial.print(F("Ch: "));    Serial.print(channel);Serial.print(" ");
    Serial.print(F("Freq: "));    Serial.print(freq);Serial.println(" ");

  }

  // Check Lora RX
  lora.update();

  recvStatus = lora.readDataByte(outStr);
  if (recvStatus) {
    newmessage = true;
    int counter = 0;
    port = lora.getFramePortRx();
    channel = lora.getChannelRx();
    freq = lora.getChannelRxFreq(channel);

    for (int i = 0; i < recvStatus; i++)
    {
      if (((outStr[i] >= 32) && (outStr[i] <= 126)) || (outStr[i] == 10) || (outStr[i] == 13))
        counter++;
    }
    if (port != 0)
    {
      if (counter == recvStatus)
      {
        Serial.print(F("Received String : "));
        for (int i = 0; i < recvStatus; i++)
        {
          Serial.print(char(outStr[i]));
        }
      }
      else
      {
        Serial.print(F("Received Hex: "));
        for (int i = 0; i < recvStatus; i++)
        {
          Serial.print(outStr[i], HEX); Serial.print(" ");
        }
      }
      Serial.println();
      Serial.print(F("fport: "));    Serial.print(port);Serial.print(" ");
      Serial.print(F("Ch: "));    Serial.print(channel);Serial.print(" ");
      Serial.print(F("Freq: "));    Serial.println(freq);Serial.println(" ");
    }
    else
    {
      Serial.print(F("Received Mac Cmd : "));
      for (int i = 0; i < recvStatus; i++)
      {
        Serial.print(outStr[i], HEX); Serial.print(" ");
      }
      Serial.println();
      Serial.print(F("fport: "));    Serial.print(port);Serial.print(" ");
      Serial.print(F("Ch: "));    Serial.print(channel);Serial.print(" ");
      Serial.print(F("Freq: "));    Serial.println(freq);Serial.println(" ");
    }
  }

}


/***************************************************
* Get indoor Temp/Hum data
****************************************************/
void getSHT21()
{
  start = micros();
  sht.read();
  stop = micros();

  float tempIni = localTemp;
  float humIni = localHum;
  localTemp = sht.getTemperature();
  localHum = sht.getHumidity();
  if (isnan(localHum) || isnan(localTemp))   
  {
    localTemp = tempIni;
    localHum = humIni;
    return;
  }
}

/***************************************************
* Display Data
****************************************************/
void displayData() 
{
  Serial.print("Temp: ==> ");
  Serial.print(localTemp);
  Serial.print("  Hum ==> ");
  Serial.println(localHum);

  display.clear();  

  display.drawString(0, 0,  "temp: ");
  display.drawString(40, 0,  String(localTemp));
  display.drawString(90, 0,  "oC");
  display.drawString(0, 32, "hum:  ");
  display.drawString(40, 32,  String(localHum));
  display.drawString(90, 32,  "%");

  display.display();  
  delay(10);
}

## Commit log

2024-06-23 FEAT: update
    [arduino_Uno_Rev3-02-TH.csv]
2024-06-25 FIX: rename file
    [esp32_lora.csv]
2024-06-26 FIX :fix temp pin on tp4056 not connected to gnd and res after pin prog tp4056 not connected to gnd
2024-06-26 FEAT: add gerber file
    [copper_bottom.gbr, copper_top.gbr, drill_1_16.xln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]
2024-06-28 FIX: change fuse ptc on main power
    [esp32_lora.csv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]
2024-06-28 FIX: remove diode schotecky after psu output
    [esp32_lora.csv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]
2024-07-12 FEAT: add library for arduinbo framework
2024-07-12 DOC: update detail pin connection

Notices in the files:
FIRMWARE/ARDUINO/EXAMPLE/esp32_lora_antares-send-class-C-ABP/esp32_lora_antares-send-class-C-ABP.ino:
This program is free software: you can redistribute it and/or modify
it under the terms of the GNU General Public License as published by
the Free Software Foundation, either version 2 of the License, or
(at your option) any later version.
